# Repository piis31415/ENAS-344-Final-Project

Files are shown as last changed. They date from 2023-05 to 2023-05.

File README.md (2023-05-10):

# ENAS 344 Final Project
 My final submission for ENAS 344/MUSI 415: Musical Acoustics and Instrument Design.

# Files Included

* figs
    > Contains figures used in the paper.
* stls
    > Contains `.stl` files used for the 3D-printed parts and 3D mock-ups of the base. Note that for the Base and Pipe Holders in the actual instrument, hole measurements were shrunk by ~0.1% in order to make the parts press-fit and due to a slight difference between the actual and expected diameters of the polycarbonate pipe and thicknesses of the white plastic blocks. 
* src
    > Contains the source code uploaded to the Teensy 4.1 used to control the instrument.
* paper.pdf
    > The write-up.
* proj.fzz
    > A Fritzing sketch of the breadboard used in the project.

# Important Links

* OnShape Project Links
    * [Mouthpiece + Connector + Adapter](https://cad.onshape.com/documents/01c1951e08a2b4da94194fd3/w/c8a3f2cde021ff766d19c6d4/e/5c5e9626267aa50ed815ff77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)
    * [Base + Pipe Holders](https://cad.onshape.com/documents/14f0397e23b12ac316776f46/w/e99594dd1a8f4184cf9c8c07/e/d2b6c66a922e2fbc48e71612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)
    * [Air Splitter](https://cad.onshape.com/documents/e4b528953a7ddd8e008ac1f3/w/9a2e2994f9237454ea7a4f29/e/6ae9f23c77e9ab8b8e5d55b8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)
    * [Panel](https://cad.onshape.com/documents/fc961fa24bd56b72f056bbff/w/50433b2ad03f250eb64b72e5/e/f4e7aff35c24147821039b8d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)
* LaTeX Project Link
    * [Overleaf Project](https://www.overleaf.com/read/ckzjxfxhcryk)

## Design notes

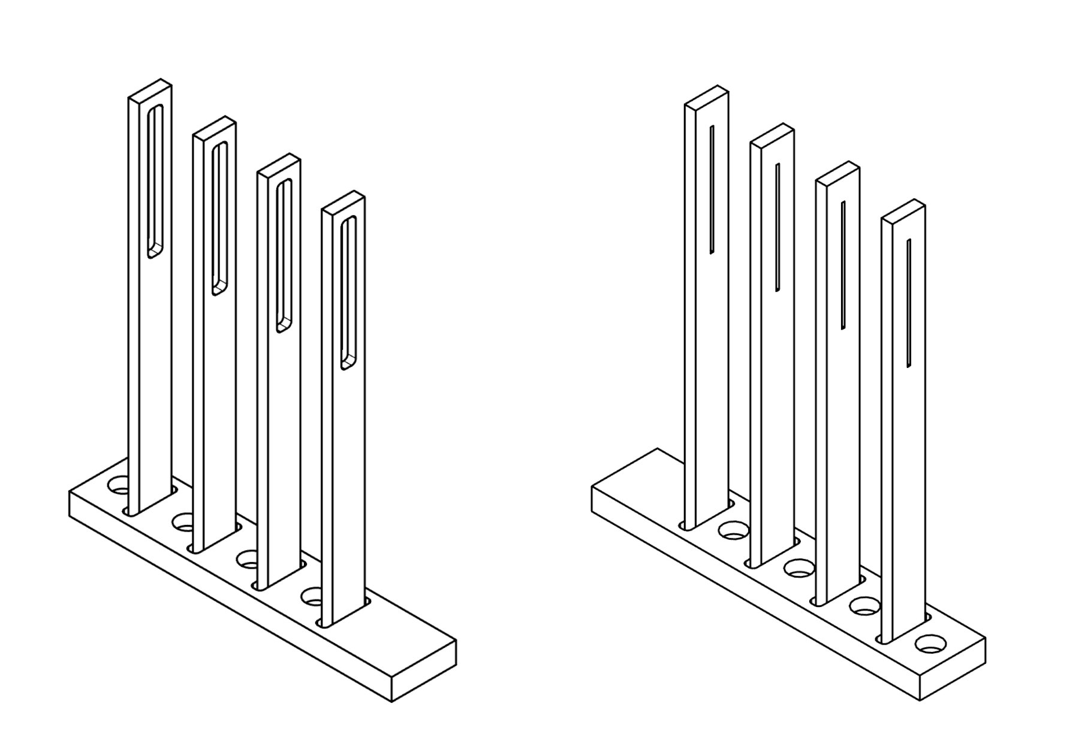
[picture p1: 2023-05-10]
figs/Figure 3 (base diagram).png

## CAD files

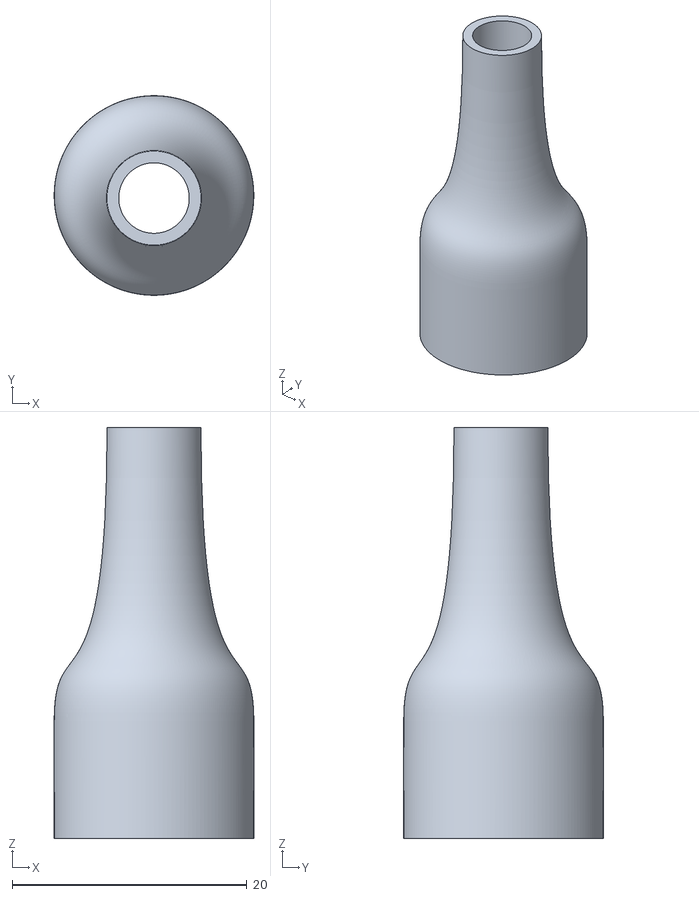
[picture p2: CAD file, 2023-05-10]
stls/Adapter.stl
17.0 x 17.0 x 35.0

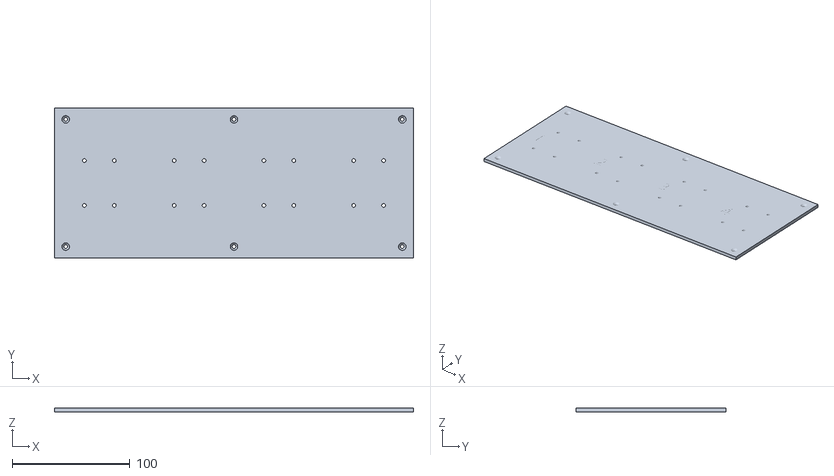
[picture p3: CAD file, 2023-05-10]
stls/Panel.stl
304.8 x 127.0 x 3.17

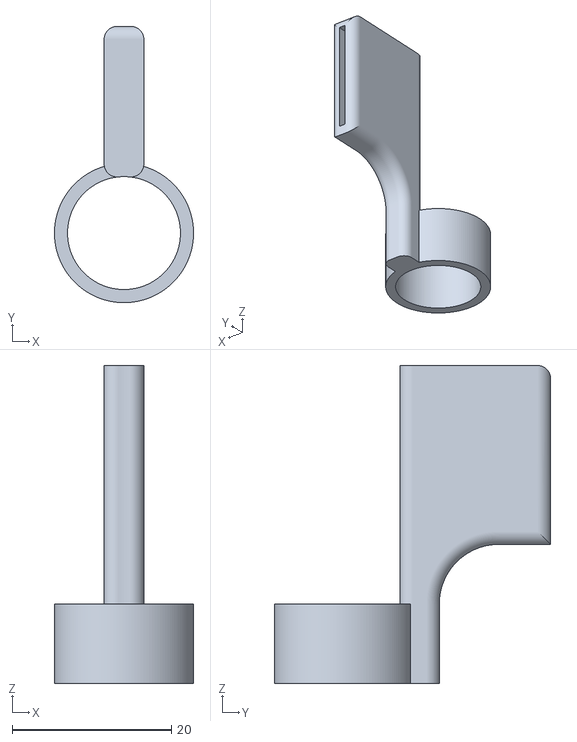
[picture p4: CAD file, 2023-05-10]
stls/Connnector.stl
17.5 x 34.7 x 40.0

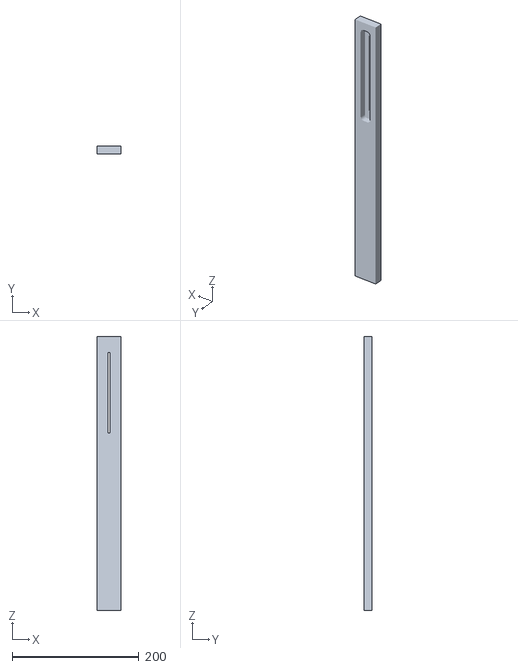
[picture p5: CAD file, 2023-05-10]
stls/Pipe Holder.stl
38.1 x 12.7 x 431.8

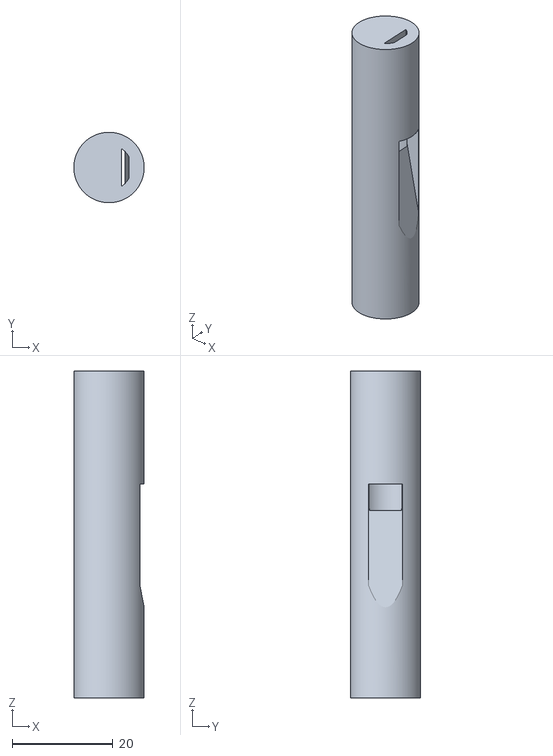
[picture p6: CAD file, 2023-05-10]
stls/Mouthpiece.stl
14.0 x 14.0 x 65.0

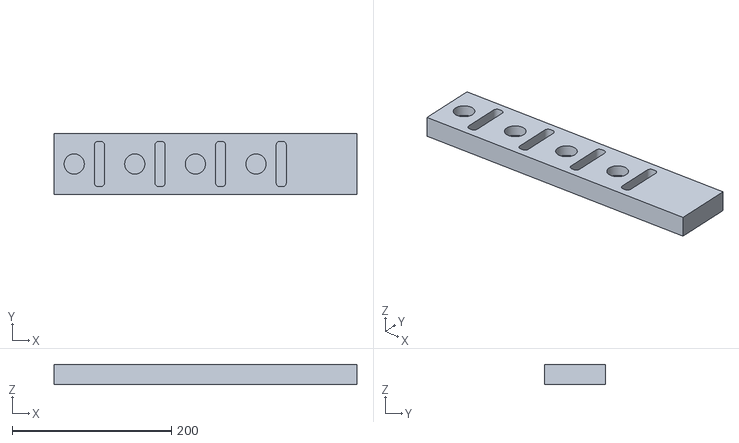
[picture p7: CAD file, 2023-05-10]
stls/Base.stl
381.0 x 76.2 x 25.4

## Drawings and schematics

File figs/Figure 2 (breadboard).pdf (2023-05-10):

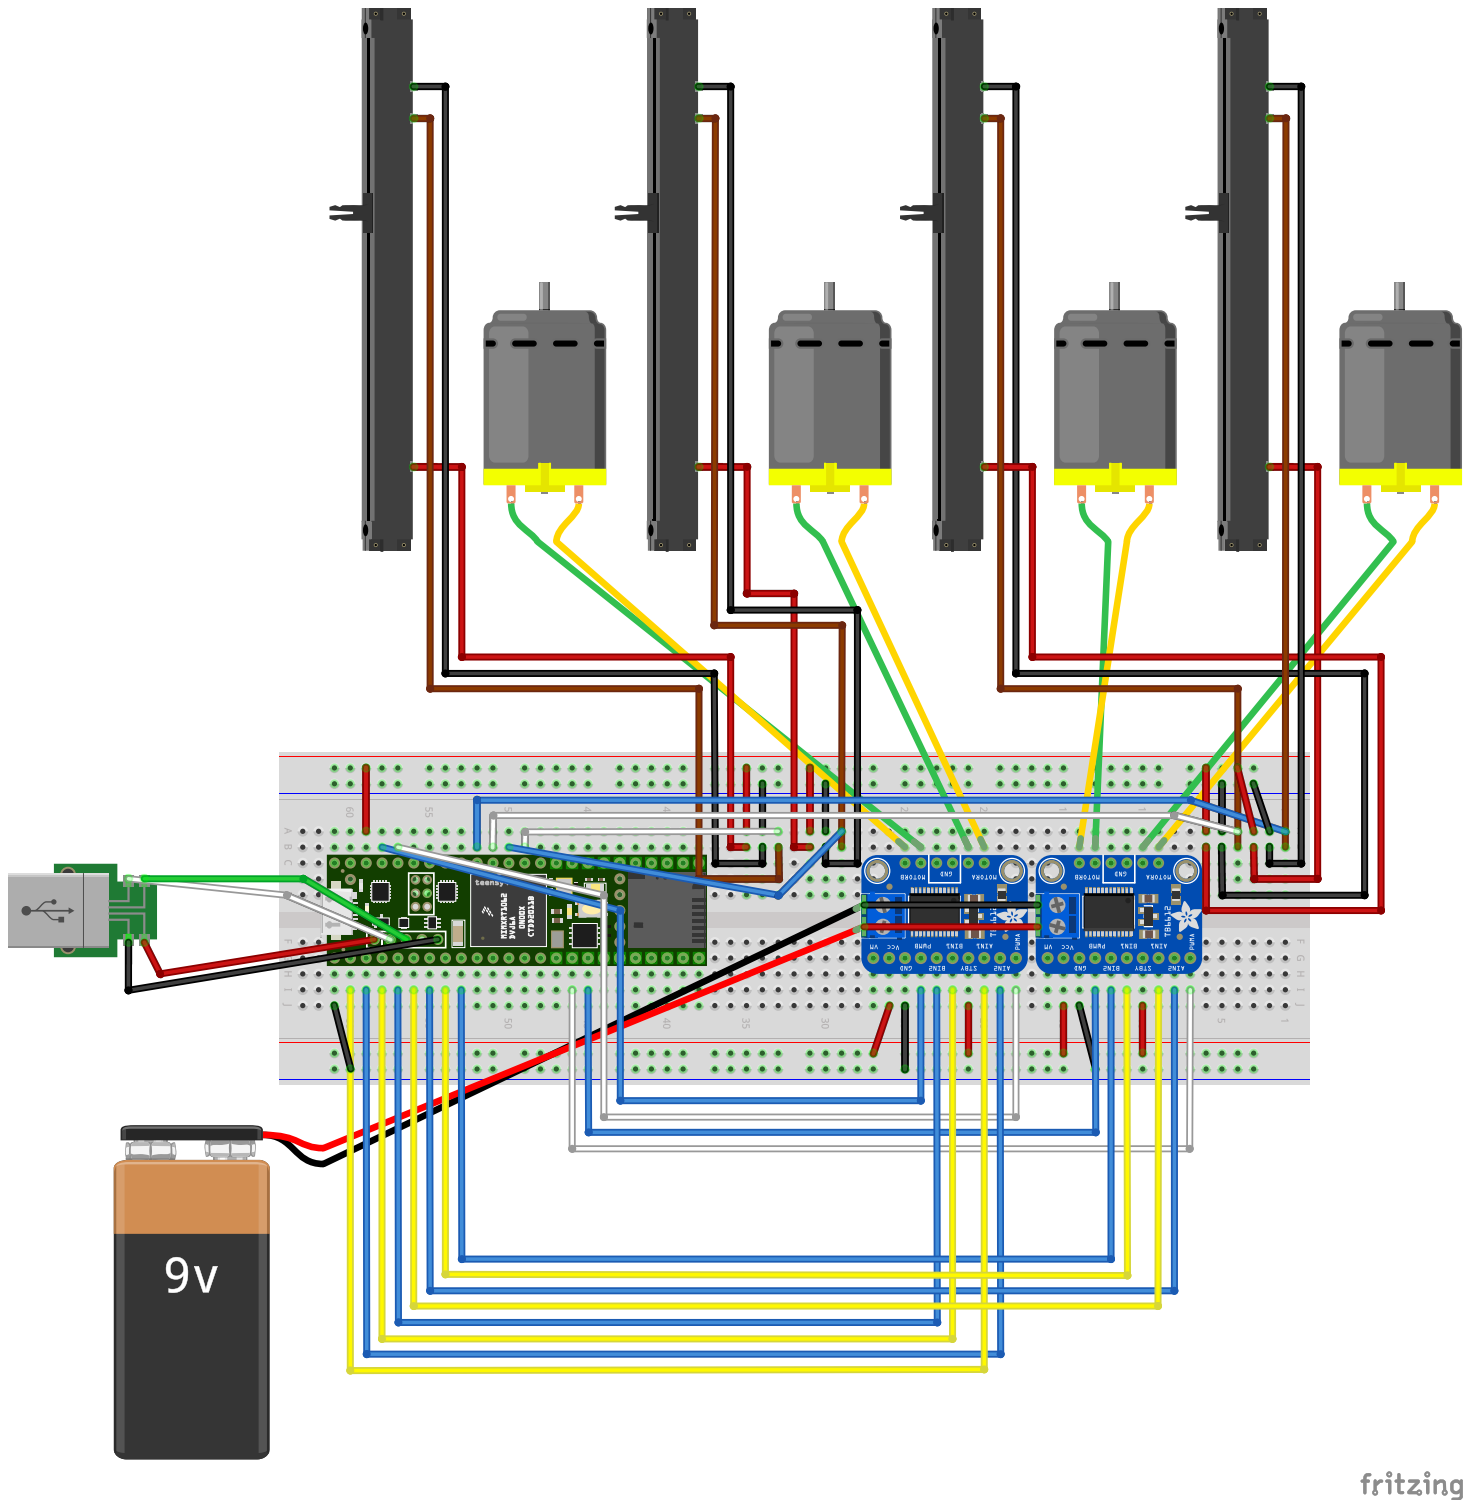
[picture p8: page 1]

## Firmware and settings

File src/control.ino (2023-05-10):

#include "USBHost_t36.h"

USBHost myusb;
MIDIDevice midi1(myusb);

/*
  SparkFun Inventor’s Kit
  Circuit 5A - Motor Basics
  Learn how to control one motor with the motor driver.
  This sketch was written by SparkFun Electronics, with lots of help from the 
Arduino community.
  This code is completely free for any use.mi
  View circuit diagram and instructions at: 
https://learn.sparkfun.com/tutorials/sparkfun-inventors-kit-experiment-guide---v41
  Download drawings and code at: https://github.com/sparkfun/SIK-Guide-Code
*/
//PIN VARIABLES
//the motor will be controlled by the motor A pins on the motor driver
const int INS1[4] = {0,2,4,6};
const int INS2[4] = {1,3,5,7};
const int PWMS[4] = {22,23,24,25};
const int pots[4] = {14,15,16,17};

const int highnotes[13] = {30, 140, 240, 360, 450, 540, 630, 700, 770, 830, 890, 950, 1000};
const int lownotes[9] = {10, 120, 260, 370, 490, 630, 720, 810, 900};
// lownotes[5] = highnotes[0] = A

typedef struct note {
  int loc;
  int dur;
} Note;

int curr = 0;
int led = 13;
char play = 0;
//VARIABLES
int motorSpeed = 255; 
int tune[4] = {0,0,0,0};

int activepipes[4] = {0,0,0,0};

int pipes[4] = {20,20,20,20};

int curr_pipe = 0;
int counter = 2;

int curr_note = -1;
int curr_off = -1;

      //starting speed for the motor
void setup() {

  Serial.begin(115200);
  
  myusb.begin();
  midi1.setHandleNoteOff(OnNoteOff);
  midi1.setHandleNoteOn(OnNoteOn);
  midi1.setHandleControlChange(OnControlChange);

  usbMIDI.setHandleNoteOff(OnNoteOff);
  usbMIDI.setHandleNoteOn(OnNoteOn_ch);
  usbMIDI.setHandleControlChange(OnControlChange);

  pinMode(led, OUTPUT);
  //set the motor control pins as outputs
  for (int i = 0; i < 4; i++) {
    pinMode(INS1[i], OUTPUT);
    pinMode(INS2[i], OUTPUT);
    pinMode(PWMS[i], OUTPUT);
  }
  pinMode(led, OUTPUT);

  analogWrite(led, HIGH);

}
void loop() {
  myusb.Task();
  midi1.read();
  usbMIDI.read();
  for (int i = 0; i < 4; i++) {
    moveTo(i, pipes[i] + tune[i]);
  }
}
/********************************************************************************/

int readPot(int p) {
  if (p == 0 || p == 1) {
    return analogRead(pots[p]);
  } else if (p == 2 || p == 3) {
    return (1023 - analogRead(pots[p]));
  } else {
    return -1;
  }
}
void spinMotor(int p, int motorSpeed){                       //function for driving the right motor
  digitalWrite (INS1[p], (motorSpeed > 0) ? HIGH : LOW);
  digitalWrite (INS2[p], (motorSpeed < 0) ? HIGH : LOW);
  analogWrite(PWMS[p], abs(motorSpeed));                 //now that the motor direction is set, drive it at the entered speed
}
char moveTo(int p, int loc) {
  int currpos = readPot(p);
  if (abs(loc - currpos) <= 15) {
    spinMotor(p, 0);
    return 1;
  }
  if (currpos < loc) {
    spinMotor(p, 255);
    return 0;
  } else {
    spinMotor(p, -255);
    return 0;
  }
}

void OnNoteOn(byte channel, byte note, byte velocity)
{
  if (note >= 44 && note <= 47) {
    curr_pipe = note - 44;
  } else if (note >= 63 && note <= 71 && (curr_pipe == 1 || curr_pipe == 2)) {
    pipes[curr_pipe] = lownotes[note - 63];
  } else if (note >= 69 && note <= 81 && (curr_pipe == 0 || curr_pipe == 3)) {
    pipes[curr_pipe] = highnotes[note - 69];
  }
}

void OnNoteOff(byte channel, byte note, byte velocity)
{

}

void OnControlChange(byte channel, byte control, byte value)
{
  if (1 <= control && control <= 4) {
   tune[control-1] = map(value, 0, 127, 0, 255);
  }
}



void OnNoteOn_ch(byte channel, byte note, byte velocity)
{
  switch (channel) {
    case 1:
      if (note >= 69 && note <= 81) pipes[0] = highnotes[note - 69];
    break;
    case 2:
      if (note >= 63 && note <= 71) pipes[1] = lownotes[note - 63];
    break;
    case 3:
      if (note >= 63 && note <= 71) pipes[2] = lownotes[note - 63];
    break;
    case 4:
      if (note >= 69 && note <= 81) pipes[3] = highnotes[note - 69];
    break;
  }
}

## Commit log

2023-05-10 Initial commit (figures, paper)
    [proj.fzz]
2023-05-10 Added STL Files
    [Adapter.stl, Base.stl, Connnector.stl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]
